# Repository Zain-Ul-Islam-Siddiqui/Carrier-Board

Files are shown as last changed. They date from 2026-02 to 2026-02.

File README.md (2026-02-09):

# Parking Access Control Carrier Board ([RK3568](https://www.alibaba.com/product-detail/YT-C68-Rockchip-RK3568-Quad-Core_1601366890205.html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) Linux Platform)
## Overview

Designed and implemented a high-performance carrier board for a Rockchip RK3568 compute module, targeting smart parking access control systems with support for multiple communication protocols and peripheral devices. The board serves as a centralized controller for barrier gates, ANPR cameras, intercom systems, ticket printers, and access readers in outdoor parking installations.

The system runs embedded Linux and provides a scalable hardware platform for field technicians and system integrators to deploy intelligent parking and access control solutions with wired and wireless connectivity, multimedia support, and industrial-grade reliability.

## Description
This project delivers a commercial-grade carrier board for a quad-core ARM Cortex-A76 based compute module (RK3568), designed specifically for parking access control and automation applications. The board integrates multiple industrial interfaces including Wiegand, RS232, RS485, Ethernet, USB, relay outputs, inductive loop inputs, and camera interfaces.

The carrier board enables real-time interaction with ANPR cameras, QR readers, intercom units, ticket printers, and barrier motors while providing a Linux-based software platform for UI, networking, and cloud connectivity. It supports both HDMI and MIPI-DSI displays with capacitive touch for operator interaction.

Designed for outdoor deployment, the hardware incorporates surge protection, ESD protection, wide-temperature operation, and power backup via Li-ion battery or supercapacitor to ensure continuous operation during power disturbances.

## Key Features
- RK3568 quad-core ARM Cortex-A76 Linux compute platform
- Multi-protocol access control support (Wiegand, RS232, RS485, GPIO, USB, Ethernet)
- Dual Ethernet interfaces for intercom and ANPR camera
- HDMI and MIPI-DSI display support with capacitive touchscreen
- Integrated relay outputs for barrier gate control (8 channels)
- Inductive loop detector inputs (3 channels)
- USB and CSI camera support (CCTV / pinhole camera)
- GSM/LTE connectivity via SIM module
- Wi-Fi and Bluetooth 5.0
- On-board environmental sensors (temperature and humidity)
- Battery / supercapacitor backup power support
- Outdoor-rated design with surge, ESD, and EMI protection
- Hardware status RGB LED and provisioning LEDs

## Technologies
- Rockchip RK3568 Compute Module
- Embedded Linux
- LPDDR4 RAM (minimum 4 GB, expandable)
- eMMC Flash (minimum 32 GB)
- USB 2.0 / 3.0
- Ethernet (10/100/1000 Mbps)
- HDMI + MIPI-DSI
- CSI Camera Interface
- GSM/LTE modem
- RS232 / RS485 / Wiegand
- Relays and opto-isolated GPIO
- Altium Designer

## Contribution
- Carrier board schematic design for RK3568 compute module
- High-speed PCB layout (DDR, HDMI, MIPI, Ethernet)
- Interface expansion for industrial IO (Wiegand, RS232, RS485, relays, GPIO)
- ESD, surge, and protection circuitry design
- Integration of GSM/LTE module and SIM interface
- Hardware bring-up preparation and validation planning

## Access Control Interfaces
Wiegand (1 primary + 1 optional)
RS232 (1 channel)
RS485 (1 channel)
Inductive loop detector (3 inputs)
Barrier gate control relays (8 outputs)
Activation LED (1 GPIO)
Status RGB LEDs (up to 6)

## Cameras & Imaging
ANPR camera via Ethernet
CCTV / pinhole camera via USB or CSI

## User Interface
HDMI display output
MIPI-DSI capacitive touchscreen
Optional action buttons (4 GPIO)
Intercom action button (1 GPIO)

## Connectivity
Dual Ethernet
USB (4 ports)
GSM/LTE with SIM card
Optional Wi-Fi & Bluetooth 5.0

## Audio
Microphone input
Speaker output

## Storage
eMMC (32 GB)
SD card slot (up to 512 GB)

## Electrical Specifications
- CPU: Quad-core ARM Cortex-A76 @ 2.4 GHz
- RAM: 4 GB LPDDR4 (expandable up to 32 GB)
- Storage: 32 GB eMMC + SD card
- Power Input: 12–24 V DC
- Backup Power: Li-ion battery

## Protection:
- Reverse polarity protection
- ESD protection on all IO
- Surge protection on Ethernet and inductive loop inputs
- EMI filtering

## Environmental Specifications
- Operating Temperature: -20°C to +65°C
- Humidity: 0% to 98% (non-condensing)
- Deployment: Outdoor parking systems
- Compliance Targets: CE & FCC

## PCB
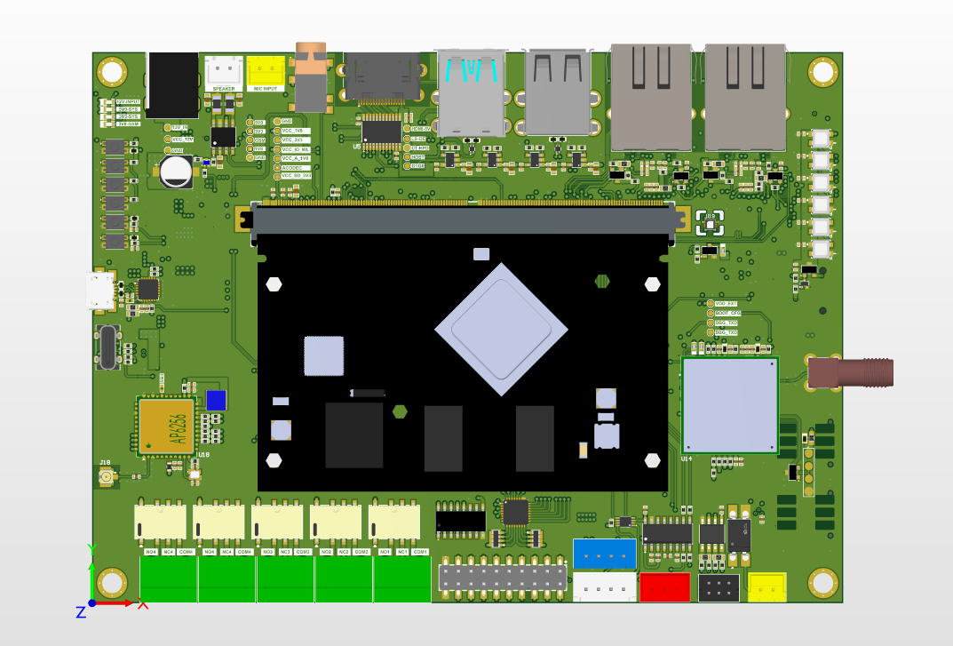
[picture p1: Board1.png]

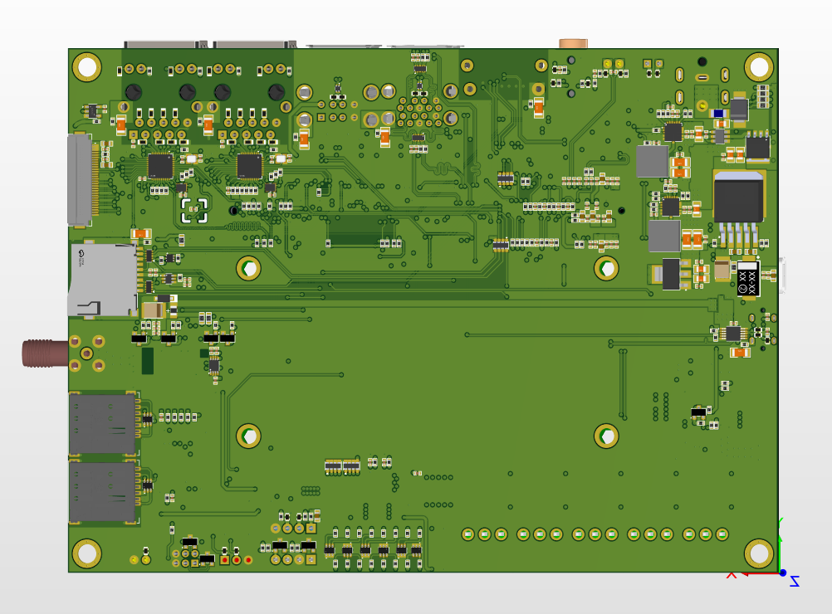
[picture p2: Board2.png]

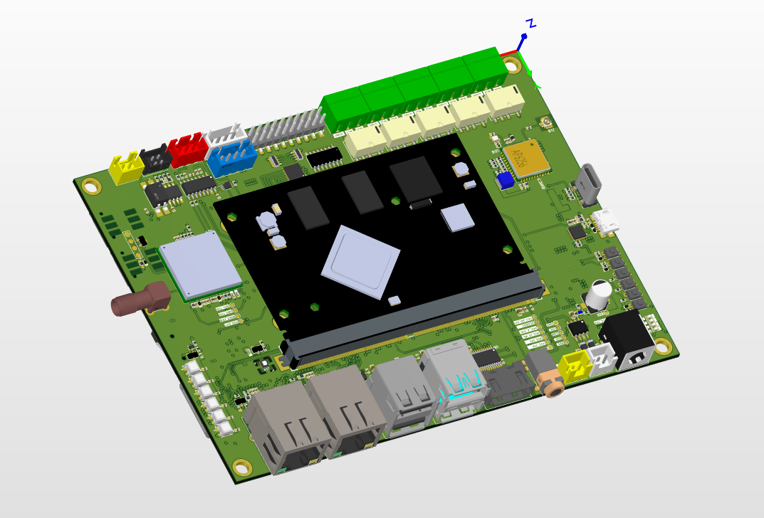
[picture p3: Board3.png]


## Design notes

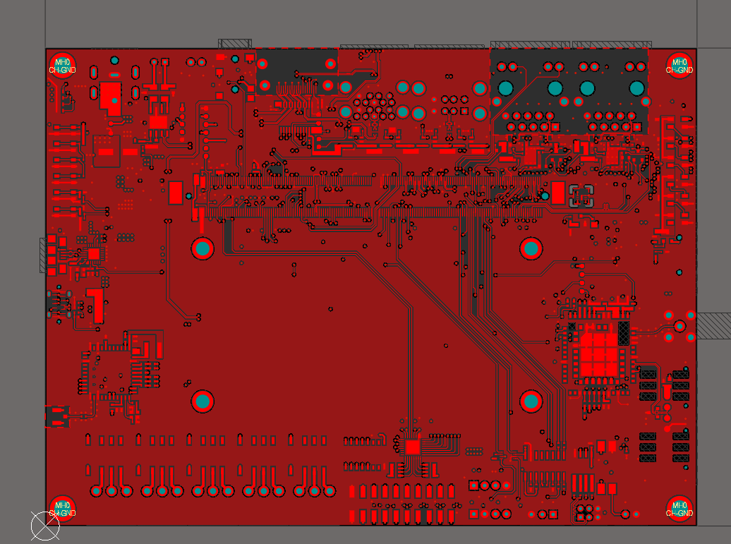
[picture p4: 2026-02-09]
Deliverables/Renderings/2D_Top_View.PNG

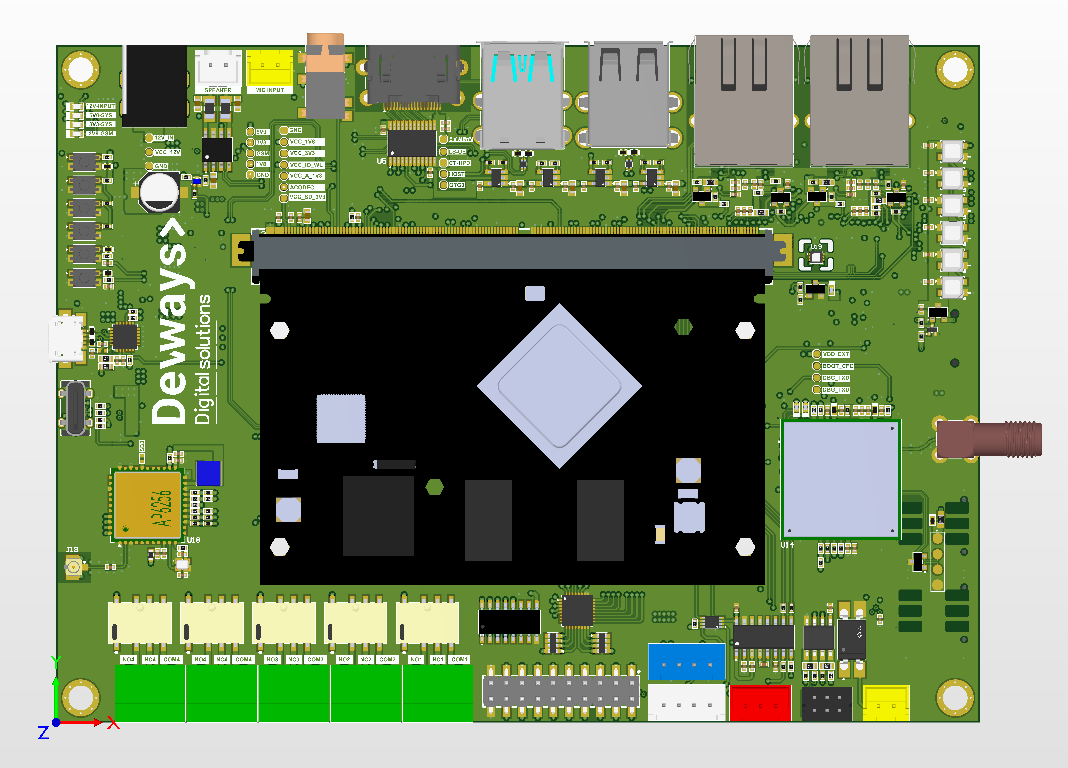
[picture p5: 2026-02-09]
Deliverables/Renderings/3D_Top_View.PNG

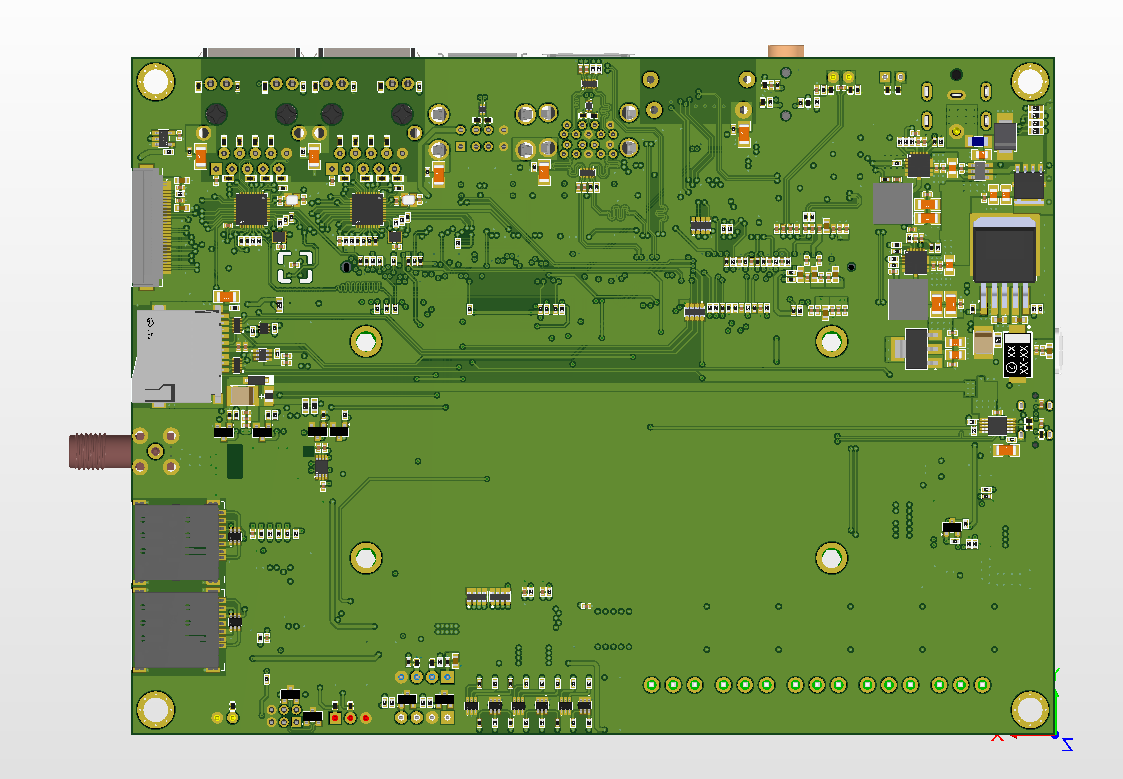
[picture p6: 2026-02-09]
Deliverables/Renderings/3D_Bottom_View.PNG

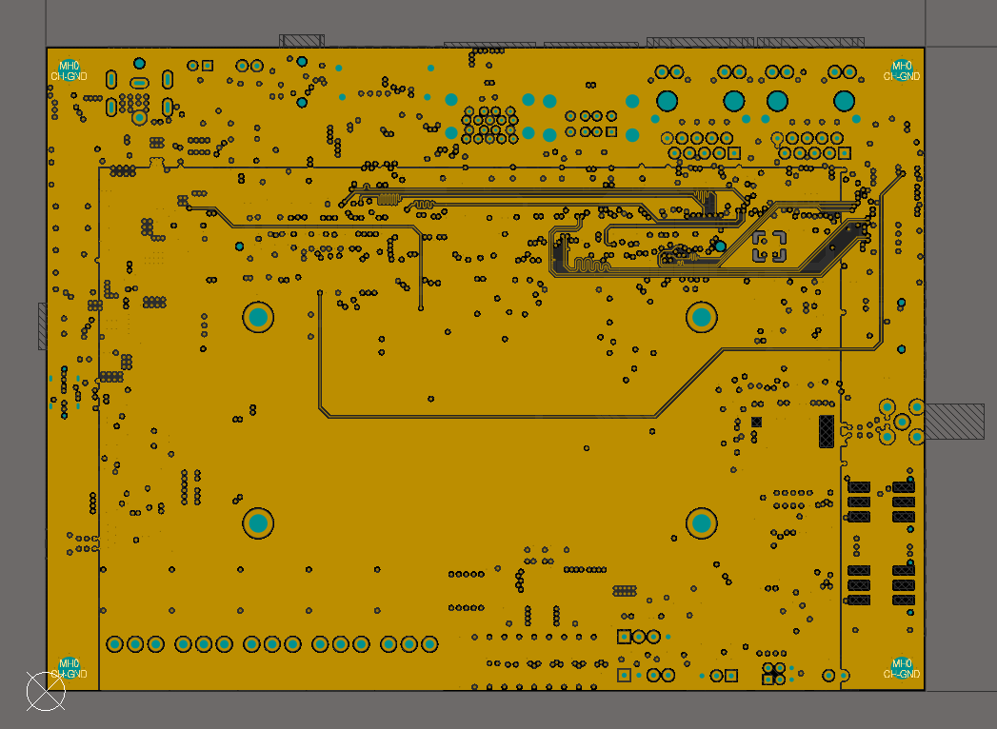
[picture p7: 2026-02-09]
Deliverables/Renderings/2D_L2_View.png

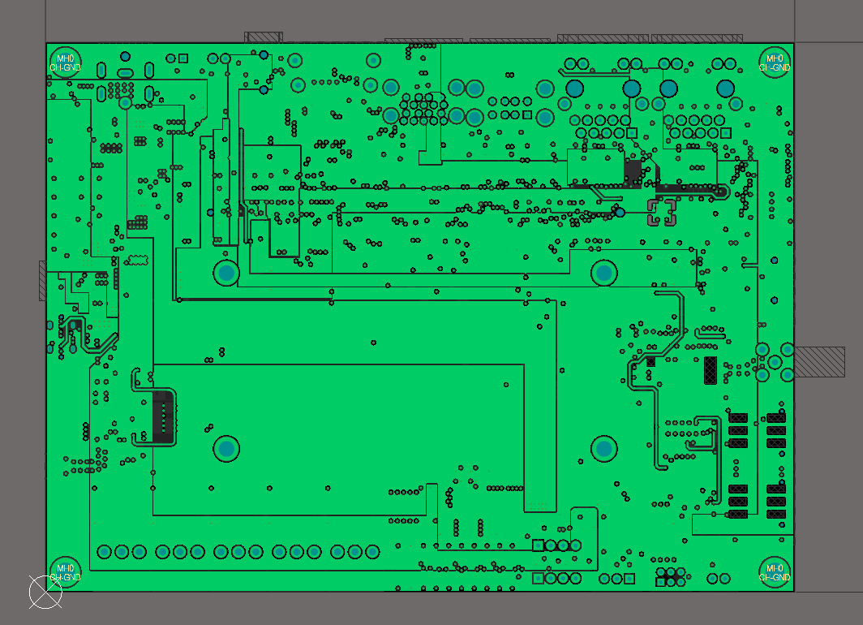
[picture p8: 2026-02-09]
Deliverables/Renderings/2D_L4_View.png

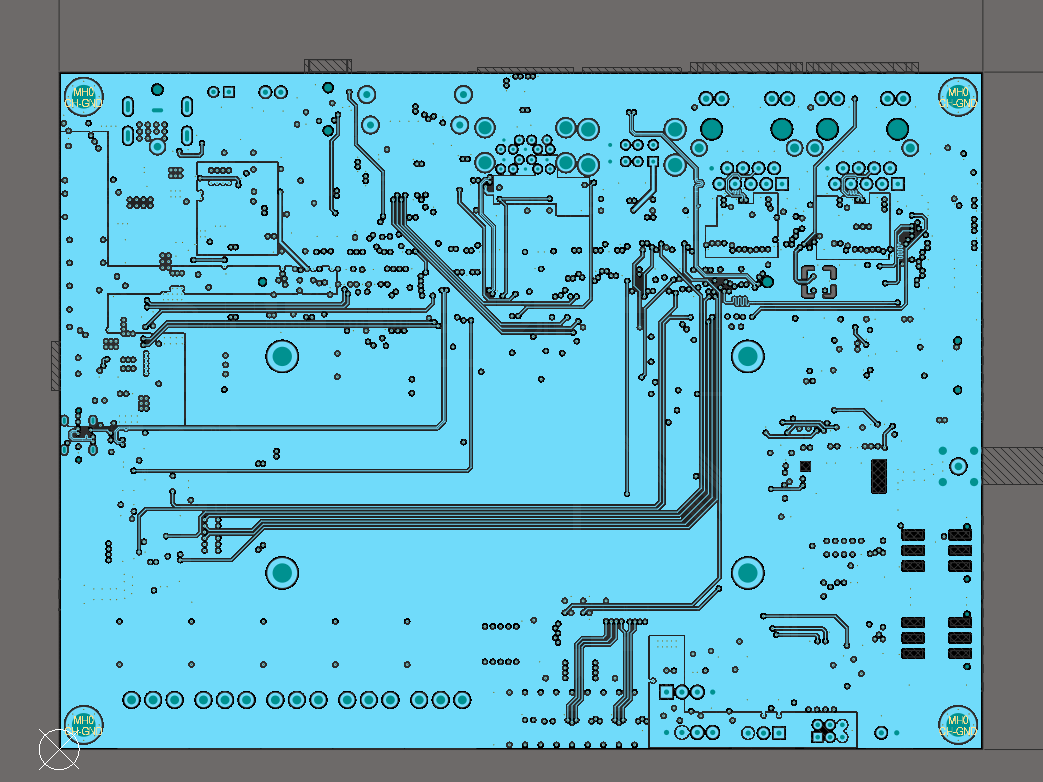
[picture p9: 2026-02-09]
Deliverables/Renderings/2D_L3_View.png

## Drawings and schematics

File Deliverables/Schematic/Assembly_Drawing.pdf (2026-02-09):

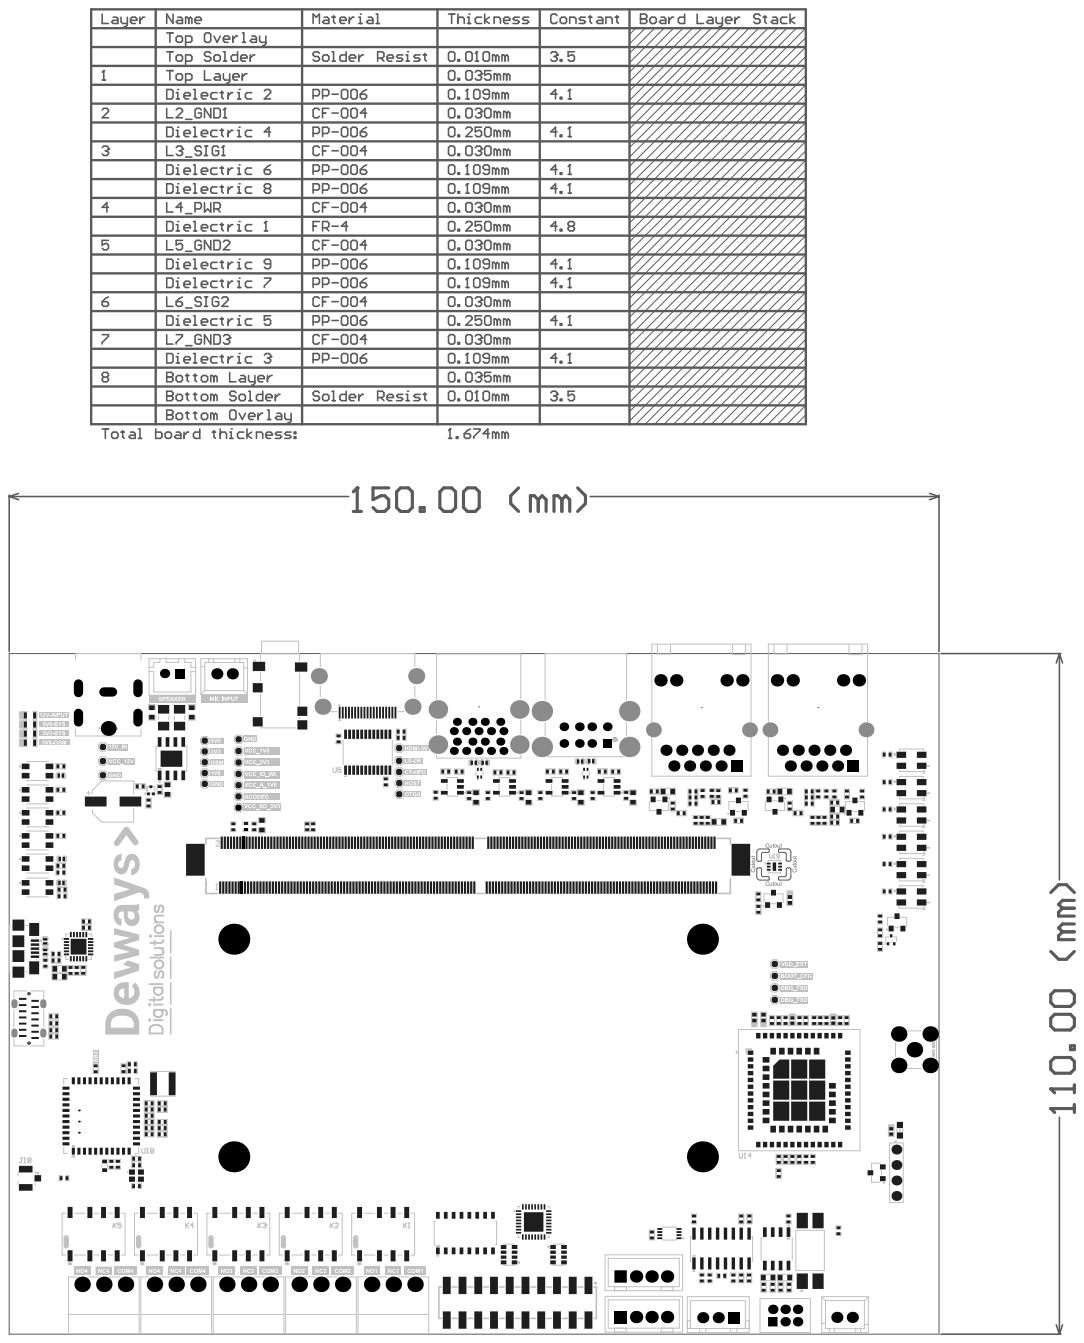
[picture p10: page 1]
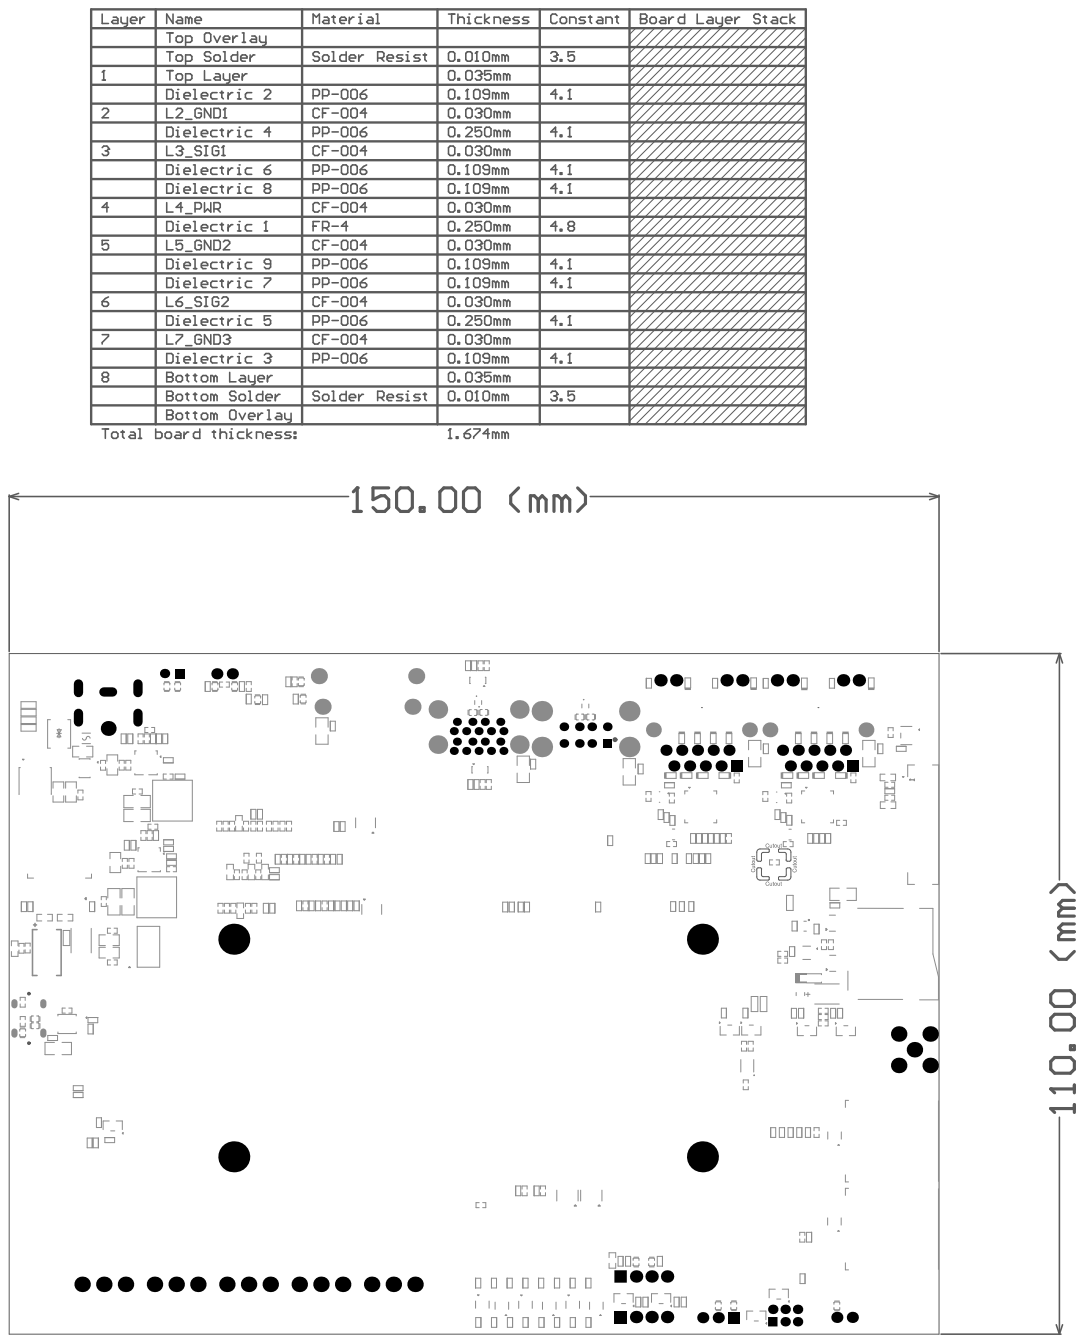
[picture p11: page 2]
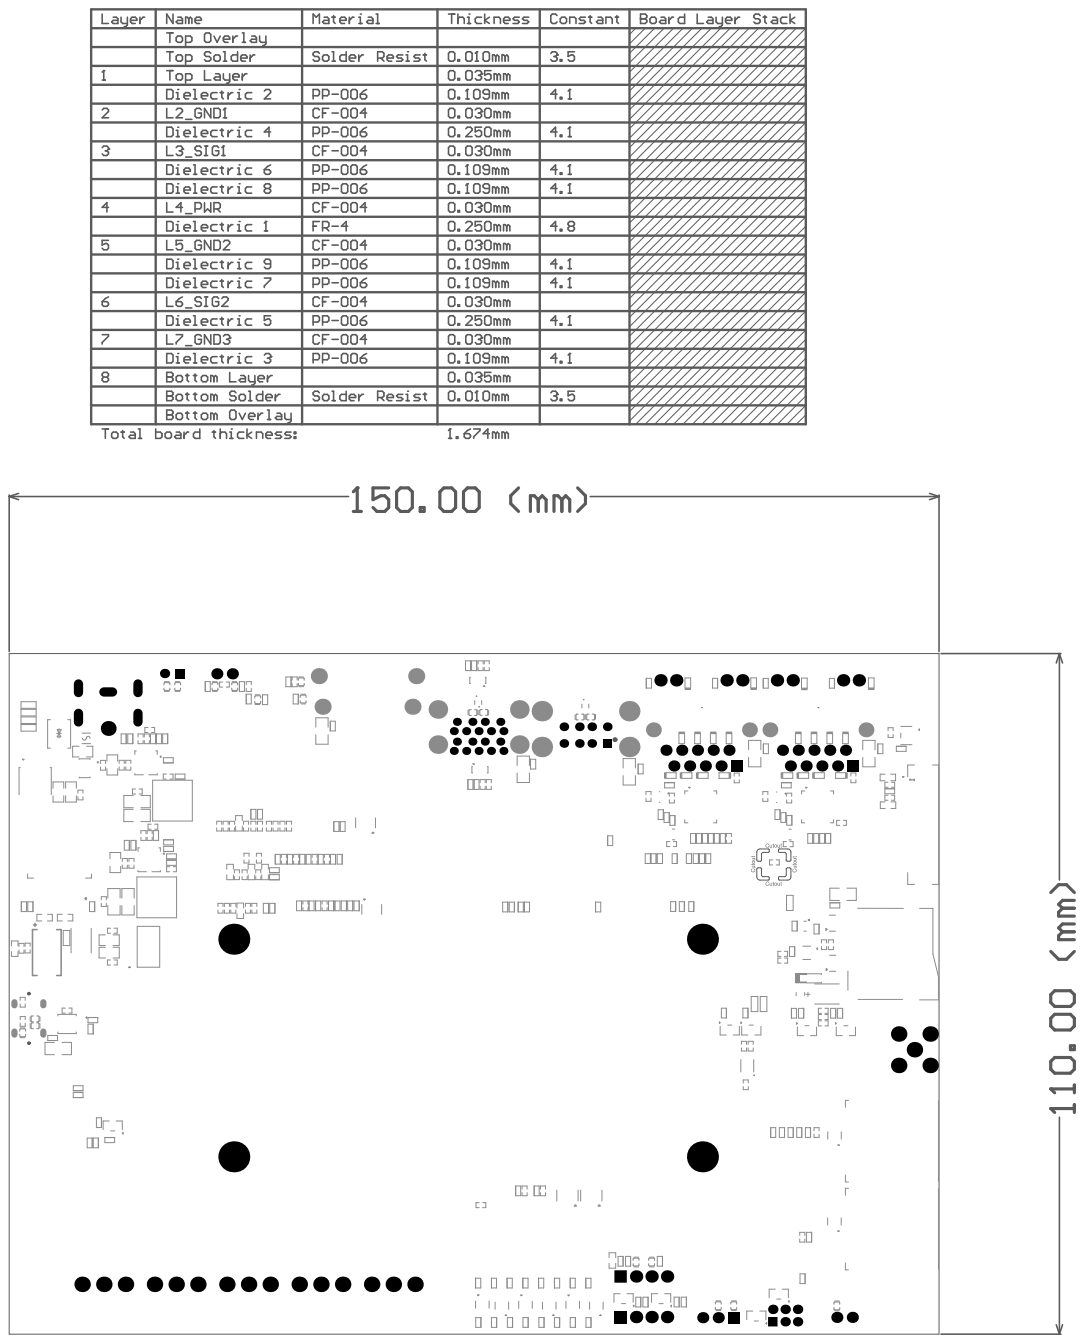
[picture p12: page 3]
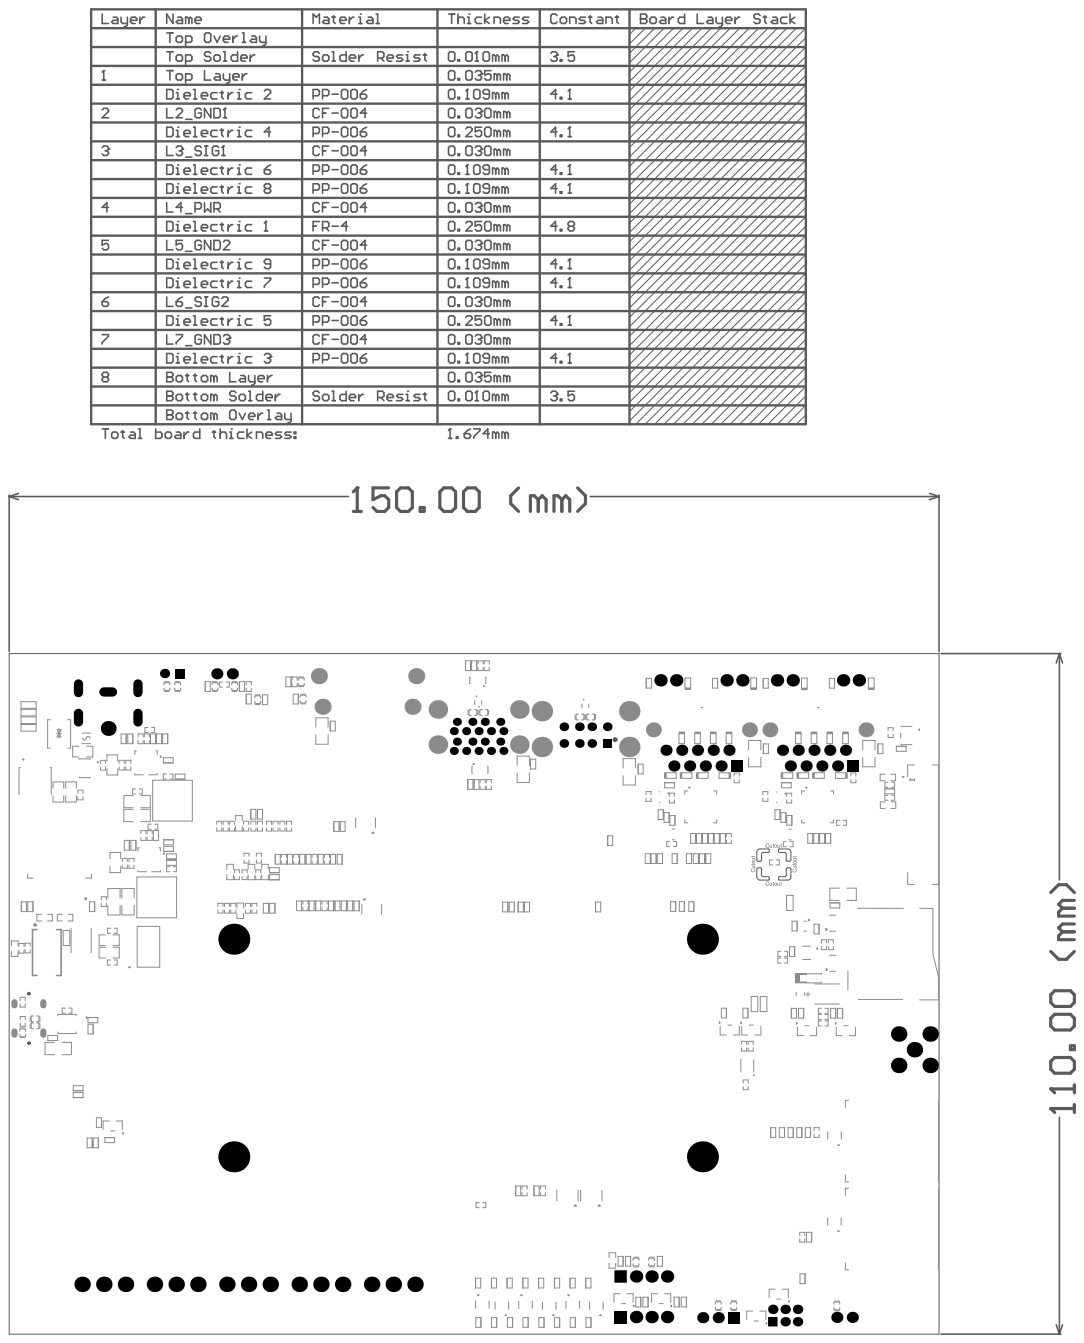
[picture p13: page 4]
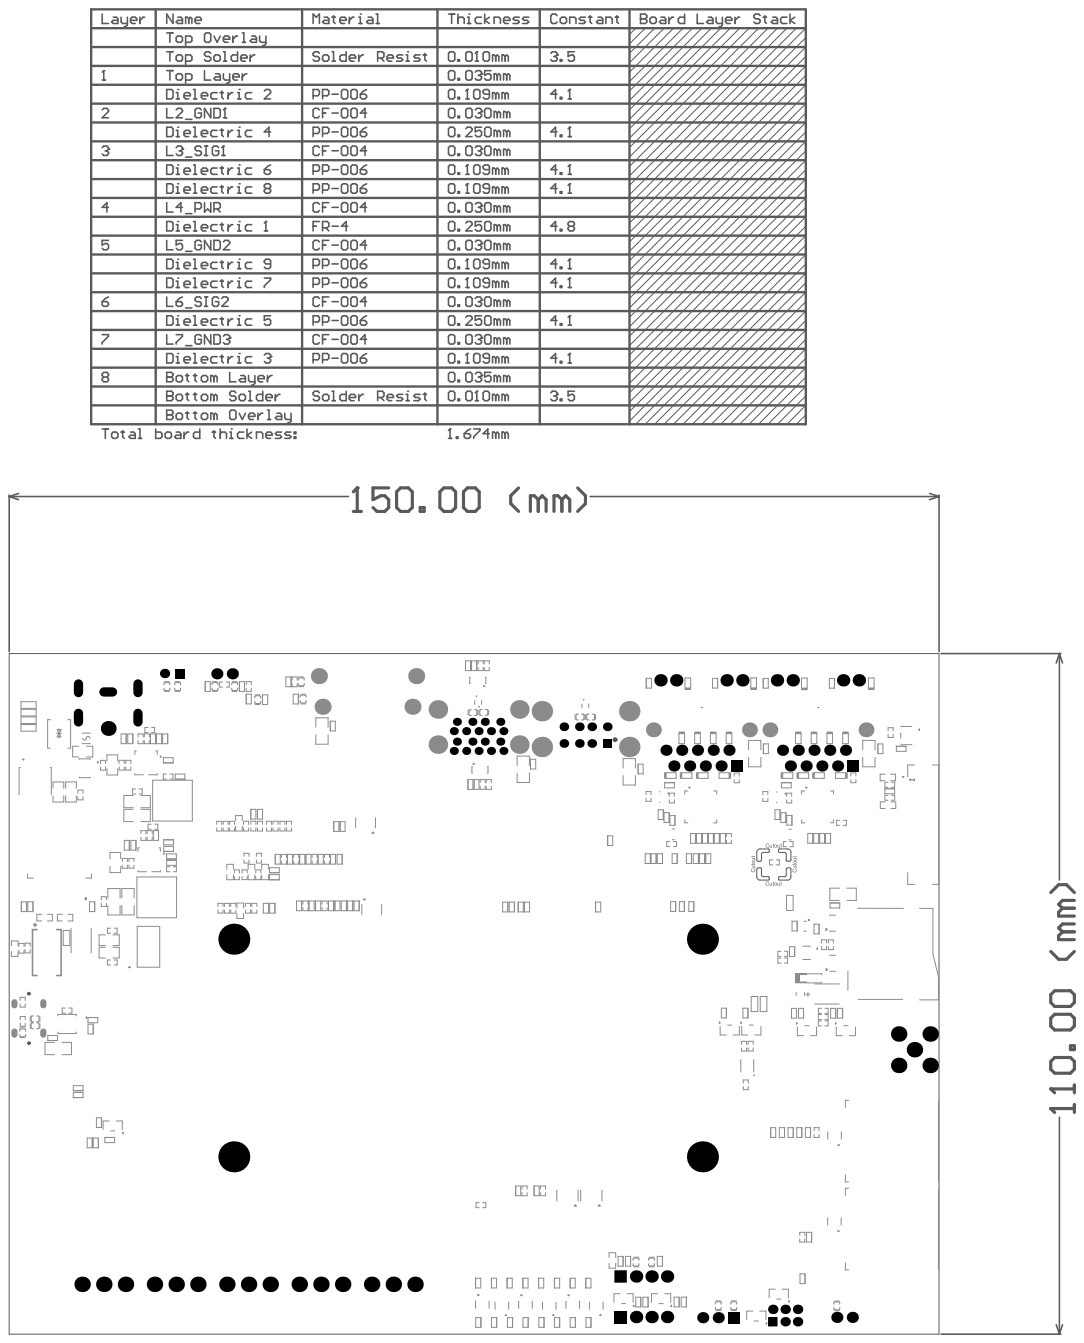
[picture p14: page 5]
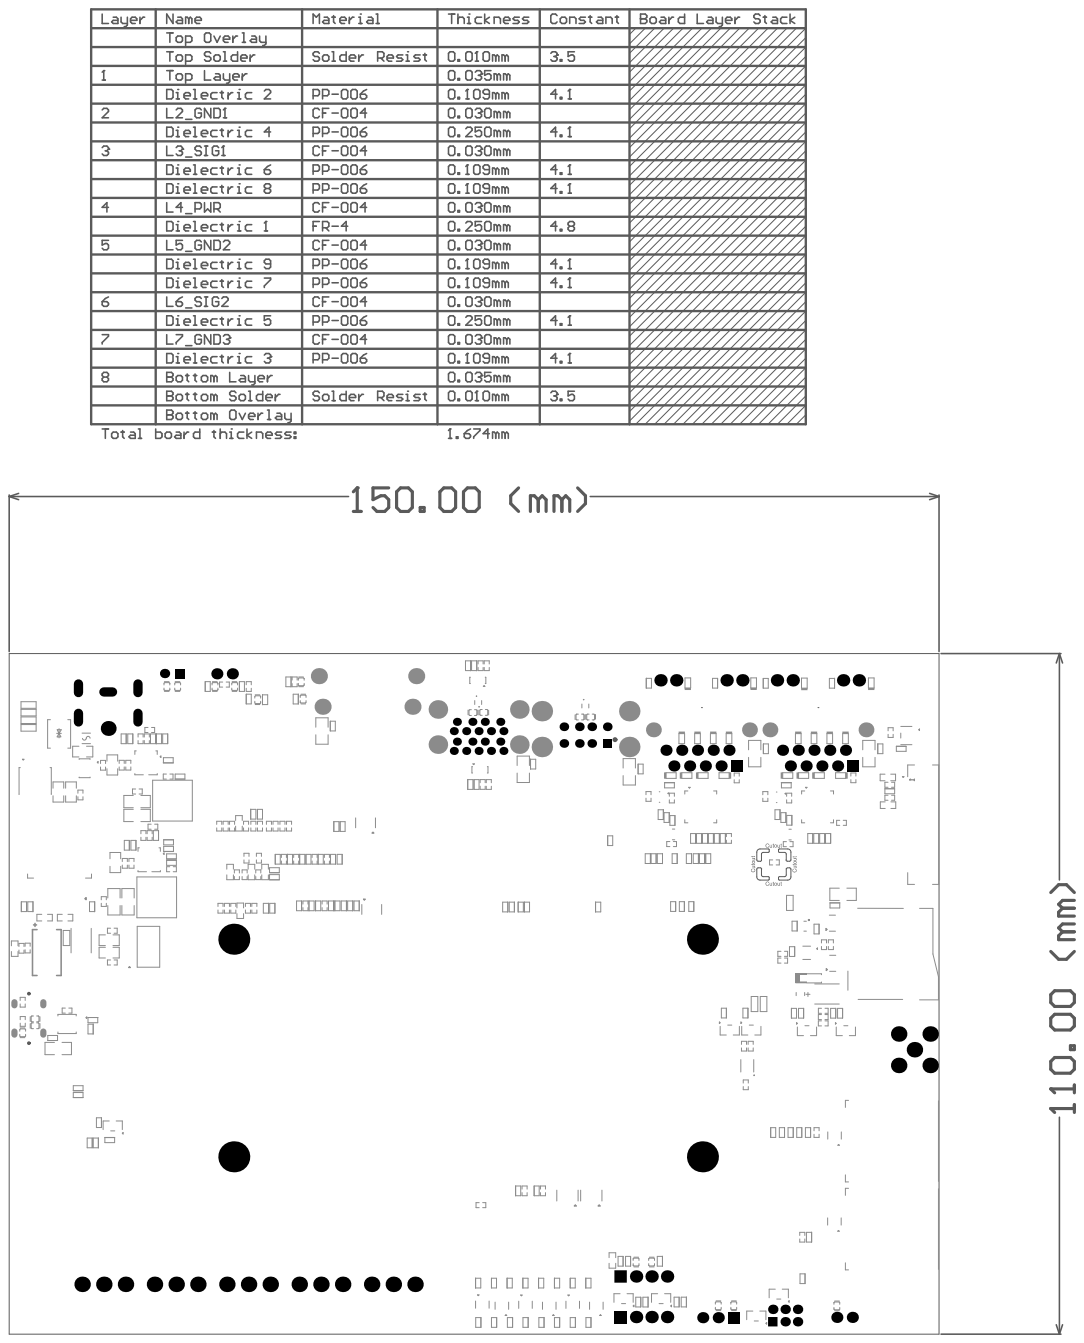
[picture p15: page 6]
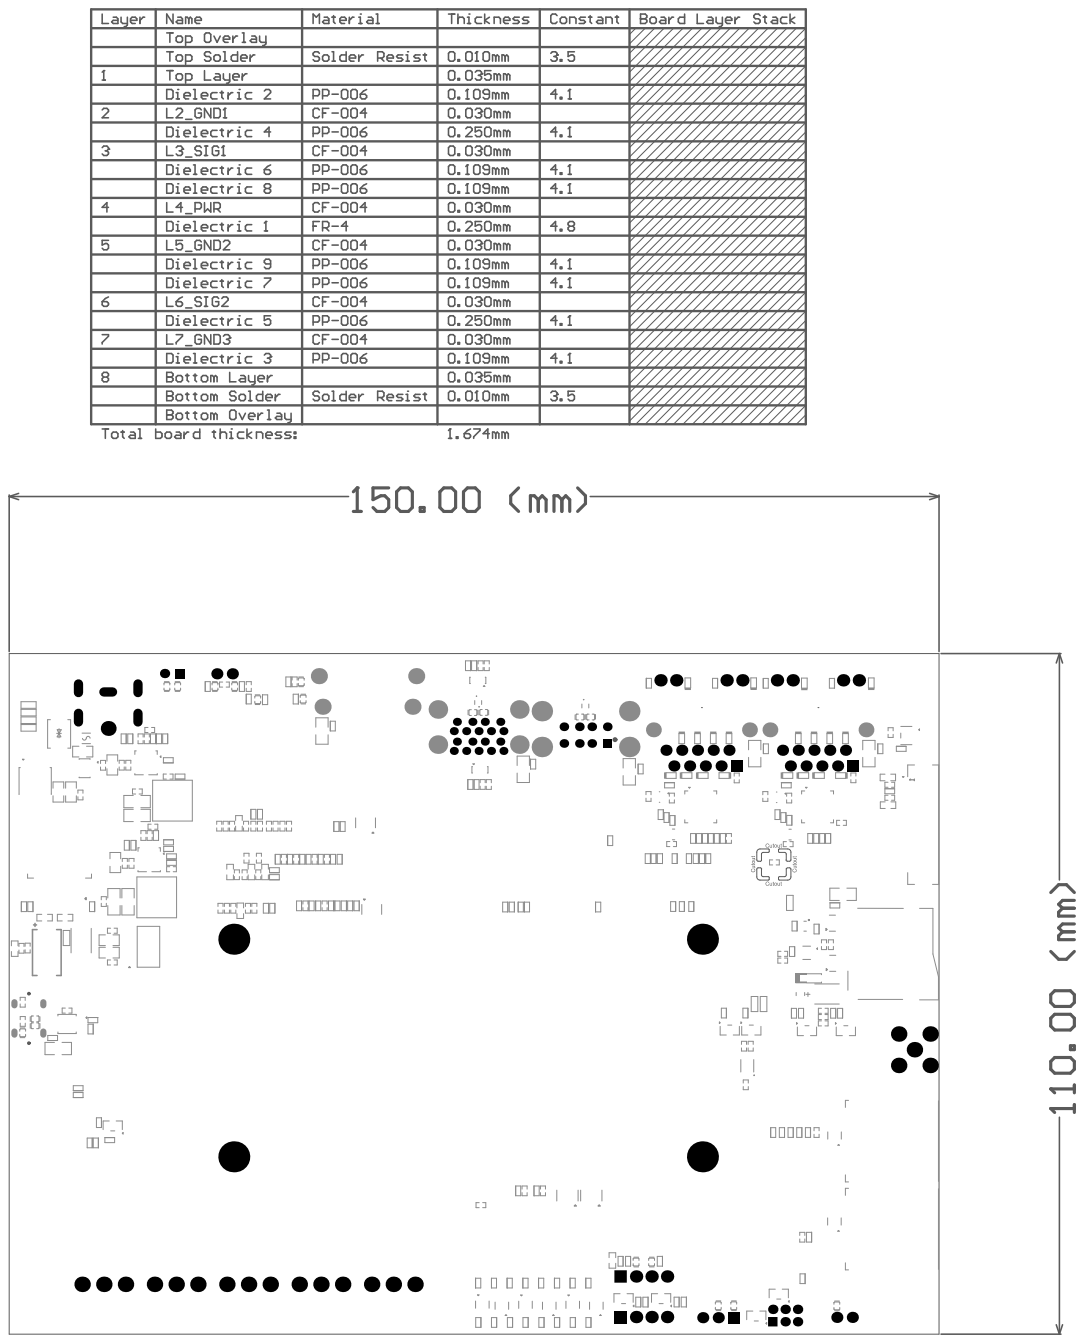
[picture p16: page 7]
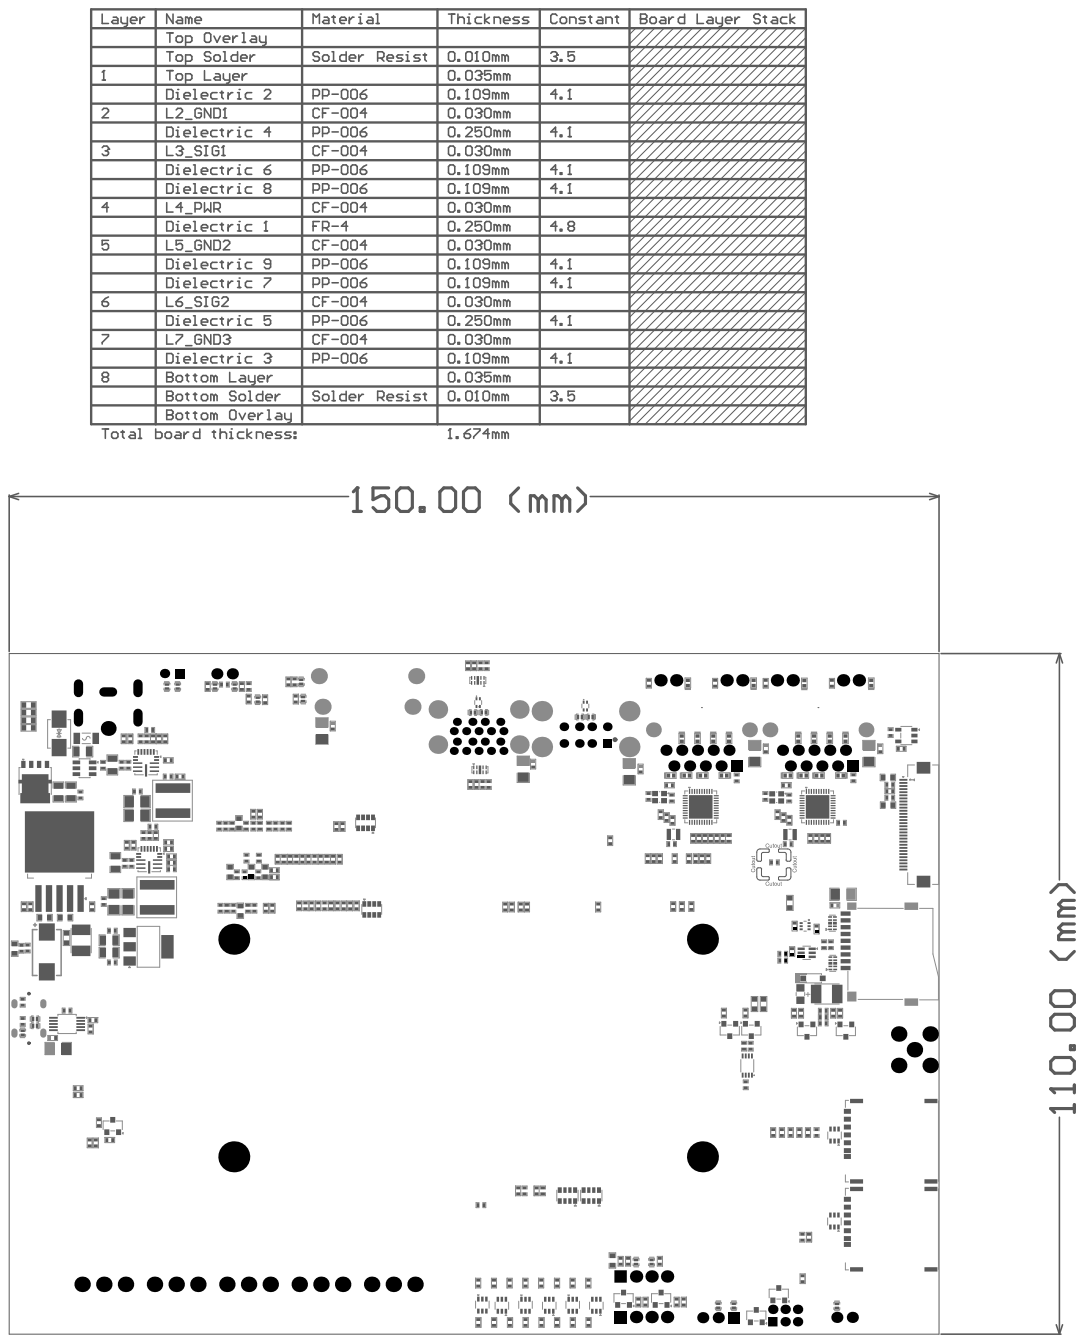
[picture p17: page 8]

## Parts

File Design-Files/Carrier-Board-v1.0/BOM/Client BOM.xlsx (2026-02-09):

# | Item Type | Designator | Description | Footprint | Manufacturer Part Number | Manufacturer | Value | Quantity | Quantity (3 Boards) | Links | Unit Cost (3 Boards) | Total Cost (3 Boards) | Remarks
1 | Capacitor | C1, C3, C4, C6, C7, C8, C9, C11, C12, C13, C14, C15, C16, C17, C18, C21, C22, C23, C27, C30, C34, C55, C65, C66, C67, C70, C71, C72, C75, C76, C78, C81, C84, C85, C88, C89, C91, C92, C93, C94, C95, C96, C97, C98, C100, C101, C103, C104, C106, C107, C109, C110, C111, C113, C114, C115, C118, C119, C120, C122, C126, C129, C131, C134, C135, C136, C137, C141, C143, C147, C148, C149, C152, C153, C154, C155, C158, C167, C168, C169, C180, C181, C182, C183, C184, C185, C186, C187, C188, C189, C190, C191, C192, C193, C194, C199, C204 | CAP CER 0.1UF 16V X5R 0402 | Cap-0402 | CC0402KRX5R7BB104 | Yageo | 100nF | 97 | 291 | Digikey (https://www.digikey.com/en/products/detail/yageo/CC0402KRX5R7BB104/2103085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) | $0.0107 | $3.1137
2 | Capacitor | C2, C165 | CAP CER 100PF 50V C0G/NPO 0402 | Cap-0402 | CC0402JRNPO9BN101 | Yageo | 100pF | 2 | 6 | Digikey (https://www.digikey.com/en/products/detail/yageo/CC0402JRNPO9BN101/302758) | $0.1000 | $0.6000
3 | Capacitor | C5, C10, C24, C31, C125, C142, C203 | CAP CER 1000PF 2KV X7R 1206 | Cap-1206 | CC1206KKX7RDBB102 | Yageo | 1nF | 7 | 21 | Digikey (https://www.digikey.com/en/products/detail/yageo/CC1206KKX7RDBB102/2833652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) | $0.2090 | $4.3890
4 | Capacitor | C19, C25, C28, C32 | CAP CER 1UF 16V X5R 0402 | Cap-0402 | CC0402KRX5R7BB105 | Yageo | 1uF | 4 | 12 | Digikey (https://www.digikey.com/en/products/detail/yageo/CC0402KRX5R7BB105/5195100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) | $0.1450 | $1.7400
5 | Capacitor | C20, C26, C29, C33 | CAP CER 10UF 16V X5R 0603 | Cap-0603 | CC0603KRX5R7BB106 | Yageo | 10uF | 4 | 12 | Digikey (https://www.digikey.com/en/products/detail/yageo/CC0603KRX5R7BB106/7164370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) | $0.4560 | $5.4720
6 | Capacitor | C35, C36, C38 | CAP CER 4.7UF 50V X5R 0805 | Cap-0805 | GRM21BR61H475KE51L | Murata | 4.7uf | 3 | 9 | Digikey (https://www.digikey.com/en/products/detail/murata-electronics/GRM21BR61H475KE51L/4905540) | $0.2800 | $2.5200
7 | Capacitor | C37, C68, C80, C166 | CAP CER 1UF 25V X5R 0402 | Cap-0402 | CC0402KRX5R8BB105 | Yageo | 1uF | 4 | 12 | Digikey (https://www.digikey.com/en/products/detail/yageo/CC0402KRX5R8BB105/5195107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) | $0.1730 | $2.0760
8 | Capacitor | C39, C40, C42, C43, C46, C50, C52, C53, C57, C124, C130, C177, C179 | CAP CER 0.1UF 50V X7R 0402 | cap-0402 | C1005X7R1H104KT000F | TDK | 100nF | 13 | 39 | Digikey (https://www.digikey.com/en/products/detail/tdk-corporation/C1005X7R1H104K050BB/2443410) | $0.0560 | $2.1840
9 | Capacitor | C41, C51, C176, C178 | CAP CER 10UF 50V X5R 0805 | Cap-0805 | GRM21BR61H106ME43L | Murata | 10uF | 4 | 12 | Digikey (https://www.digikey.com/en/products/detail/murata-electronics/GRM21BR61H106ME43L/10326317) | $0.2240 | $2.6880
10 | Capacitor | C44, C45, C54, C56 | CAP CER 47UF 25V X5R 1206 | Cap-1206 | GRM31CR61E476ME44L | Murata | 47uF | 4 | 12 | Digikey (https://www.digikey.com/en/products/detail/murata-electronics/GRM31CR61E476ME44K/13910174) | $0.7530 | $9.0360
11 | Capacitor | C47, C59 | CAP CER 2.2UF 25V X5R 0402 | Cap-0402 | GRM155R61E225KE11D | Murata | 2.2uf | 2 | 6 | Digikey (https://www.digikey.com/en/products/detail/murata-electronics/GRM155R61E225KE11D/4905143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) | $0.2200 | $1.3200
12 | Capacitor | C48, C60 | CAP CER 1000PF 25V X7R 0402 | Cap-0402 | CC0402KRX7R8BB102 | Yageo | 1000pF | 2 | 6 | Digikey (https://www.digikey.com/en/products/detail/yageo/CC0402KRX7R8BB102/5195121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) | $0.1000 | $0.6000
13 | Capacitor | C49, C61 | CAP CER 3.9PF 50V C0G/NPO 0402 | Cap-0402 | CC0402BRNPO9BN3R9 | Yageo | 3.9pF | 2 | 6 | Digikey (https://www.digikey.com/en/products/detail/yageo/CC0402BRNPO9BN3R9/5195031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) | $0.1000 | $0.6000
14 | Capacitor | C58, C77 | CAP CER 10PF 50V C0G/NP0 0402 | Cap-0402 | GRM1555C1H100JA01D | Murata | 10pF | 2 | 6 | Digikey (https://www.digikey.com/en/products/detail/murata-electronics/GRM1555C1H100JA01D/3661907) | $0.1000 | $0.6000
15 | Capacitor | C62 | CAP TANT 470UF 10% 10V 2917 | Case-E | TAJE477K010RNJ | Kyocera AVX | 470uF | 1 | 3 | Digikey (https://www.digikey.com/en/products/detail/kyocera-avx/TAJE477K010RNJ/563853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) | $2.3700 | $7.1100
16 | Capacitor | C63 | CAP CER 0.1UF 50V X5R 0603 | Cap-0603 | CC0603KRX5R9BB104 | Yageo | 100nF | 1 | 3 | Digikey (https://www.digikey.com/en/products/detail/yageo/CC0603KRX5R9BB104/5883729) | $0.1000 | $0.3000
17 | Capacitor | C64 | CAP CER 33PF 25V C0G/NP0 0402 | Cap-0402 | GRM1555C1E330JA01D | Murata | 33pF | 1 | 3 | Digikey (https://www.digikey.com/en/products/detail/murata-electronics/GRM1555C1E330JA01D/3693730) | $0.1000 | $0.3000
18 | Capacitor | C69, C174 | CAP TANT 100UF 20% 10V 1411 | Case-B | TAJB107M010RNJ | Kyocera AVX | 100uF | 2 | 6 | Digikey (https://www.digikey.com/en/products/detail/kyocera-avx/TAJB107M010RNJ/1469629) | $0.6900 | $4.1400
19 | Capacitor | C73, C74 | CAP CER 0.22UF 25V X5R 0402 | Cap-0402 | CC0402KRX5R8BB224 | Yageo | 220nF | 2 | 6 | Digikey (https://www.digikey.com/en/products/detail/yageo/CC0402KRX5R8BB224/5883337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) | $0.1000 | $0.6000
20 | Capacitor | C79 | CAP CER 10UF 10V X5R 0402 | Cap-0402 | CC0402MRX5R6BB106 | Yageo | 10uF | 1 | 3 | Digikey (https://www.digikey.com/en/products/detail/yageo/CC0402MRX5R6BB106/7164364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) | $0.2600 | $0.7800
21 | Capacitor | C82, C83, C127, C128, C138, C139 | CAP CER 12PF 50V C0G/NP0 0402 | Cap-0402 | GJM1555C1H120GB01D | Murata | 12pF | 6 | 18 | Digikey (https://www.digikey.com/en/products/detail/murata-electronics/GJM1555C1H120GB01D/2592851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) | $0.1900 | $3.4200
22 | Capacitor | C86, C87, C90, C99, C102, C105, C108, C112, C156, C157 | CAP CER 10UF 25V X5R 0603 | Cap-0603 | C1608X5R1E106M080AC | TDK | 10uF | 10 | 30 | Digikey (https://www.digikey.com/en/products/detail/tdk-corporation/C1608X5R1E106M080AC/3648585) | $0.2700 | $8.1000
23 | Capacitor | C116 | 100uF 50V ±20% SMD,D6.3xL7.7mm Aluminum Electrolytic Capacitors - SMD ROHS | Custom | RVT1H101M0607 | ROQANG | 100uF | 1 | 3 | LCSC (https://www.lcsc.com/product-detail/Aluminum-Electrolytic-Capacitors-SMD_ROQANG-RVT1H101M0607_C3151829.html) | $0.0568 | $0.1704
24 | Capacitor | C117, C121, C123, C132, C140, C146, C150 | CAP CER 4.7UF 10V X5R 0402 | Cap-0402 | CC0402KRX5R6BB475 | Yageo | 4.7uF | 7 | 21 | Digikey (https://www.digikey.com/en/products/detail/yageo/CC0402KRX5R6BB475/7164361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) | $0.0820 | $1.7220
25 | Capacitor | C159, C160, C161, C162, C163, C164, C198 | CAP CER 1000PF 25V X7R 0402 | Cap-0402 | CC0402KRX7R8BB102 | Yageo | 1nF | 7 | 21 | Digikey (https://www.digikey.com/en/products/detail/yageo/CC0402KRX7R8BB102/5195121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) | $0.0210 | $0.4410
26 | Capacitor | C170, C171 | CAP CER 27PF 25V C0G/NP0 0402 | Cap-0402 | 0402N270J250CT | Walsin Technologies | 27pF | 2 | 6 | Digikey (https://www.digikey.com/en/products/detail/walsin-technology-corporation/0402N270J250CT/9354788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) | $0.1000 | $0.6000
27 | Capacitor | C172, C173 | CAP CER 0.015UF 50V X7R 0402 | Cap-0402 | CC0402KRX7R9BB153 | Yageo | 15nF | 2 | 6 | Digikey (https://www.digikey.com/en/products/detail/yageo/CC0402KRX7R9BB153/5883374) | $0.1000 | $0.6000
28 | Capacitor | C175 | CAP CER 0.1UF 100V X7R 0603 | Cap-0603 | CC0603KRX7R0BB104 | Yageo | 0.1uF | 1 | 3 | Digikey (https://www.digikey.com/en/products/detail/yageo/CC0603KRX7R0BB104/3476111) | $0.1700 | $0.5100
29 | Capacitor | C195, C196 | CAP CER 1000PF 25V C0G/NPO 0603 | CAP-0603 | CC0603JRNPO8BN102 | Yageo | 1000pF | 2 | 6 | Digikey (https://www.digikey.com/en/products/detail/yageo/CC0603JRNPO8BN102/2103080) | $0.1000 | $0.6000
30 | Capacitor | C197 | CAP CER 1UF 25V X5R 0603 | Cap-0603 | CC0603KRX5R8BB105 | Yageo | 1uF | 1 | 3 | Digikey (https://www.digikey.com/en/products/detail/yageo/CC0603KRX5R8BB105/2833610) | $0.1000 | $0.3000
31 | Surge Protection (TVS/ESD) | D1, D2 | TVS DIODE 7V/12V 14V/26V SOT23-3 | SOT-23 | CDSOT23-SM712 | Bourns | - | 2 | 6 | Digikey (https://www.digikey.com/en/products/detail/bourns-inc/CDSOT23-SM712/1630592) | $1.5000 | $9.0000
32 | Diode | D3, D4, D7, D8, D9, D10, D11, D12, D13, D14, D22, D23, D24, D25, D48, D49, D50, D51, D53, D54, D55, D56, D57, D61, D64, D65, D66, D68 | DFN1006-2(0402) ESD Protection Devices ROHS | DFN1006-2L (Bi-Directional) | ESD5451N | TECH PUBLIC | - | 28 | 84 | LCSC (https://www.lcsc.com/product-detail/Electrostatic-and-Surge-Protection-TVS-span-style-background-color-ff0-ESD-span_TECH-PUBLIC-ESD5451N_C2936977.html) | $0.0083 | $0.6972
33 | Diode | D5, D6 | DFN2510-10L ESD Protection Devices ROHS | DFN2510-10L_ | ESD5344D-10/TR | WILLSEMI | - | 2 | 6 | LCSC (https://www.lcsc.com/product-detail/Electrostatic-and-Surge-Protection-TVS-span-style-background-color-ff0-ESD-span_WILLSEMI-Will-Semicon-ESD5344D-10-TR_C2396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) | $0.0626 | $0.3756
34 | Diode | D15 | TVS DIODE 33VWM 53.3VC SMB | SMB Bi Directional | SMBJ33CA-13-F | Diodes | - | 1 | 3 | Digikey (https://www.digikey.com/en/products/detail/diodes-incorporated/SMBJ33CA-13-F/814613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) | $0.3700 | $1.1100
35 | Diode | D16, D58, D59, D60, D62, D63 | DIODE ZENER ARRAY 3.3V SOT363 | SOT-363 | BZX84C3V3TS-7-F | Diodes Incorporated | - | 6 | 18 | Digikey (https://www.digikey.com/en/products/detail/diodes-incorporated/BZX84C3V3TS-7-F/1934541) | $0.3050 | $5.4900
36 | Diode | D17 | DIODE ZENER 5.1V 500MW SOD123 | SOD-123 | MMSZ5231BT1G | ON Semiconductor | - | 1 | 3 | Digikey (https://www.digikey.com/en/products/detail/onsemi/MMSZ5231BT1G/919749) | $0.2100 | $0.6300
37 | Diode | D18, D26, D27, D28, D29, D30, D31, D32, D33, D34, D35, D36, D37, D38, D39, D40, D41, D42, D43, D44, D45 | DFN1006-2 ESD Protection Devices ROHS | DFN1006-2L_ | ESD9X5VU | TECH PUBLIC | - | 21 | 63 | LCSC (https://www.lcsc.com/product-detail/Electrostatic-and-Surge-Protection-TVS-span-style-background-color-ff0-ESD-span_TECH-PUBLIC-ESD9X5VU_C2875160.html) | $0.0191 | $1.2033
38 | Diode | D19 | 16A 20V 7V 5V@Max Unidirectional SOT-23 TVS ROHS | Sot-23 | ESD5302F-3/TR | WILLSEMI | - | 1 | 3 | LCSC (https://www.lcsc.com/product-detail/Electrostatic-and-Surge-Protection-TVS-span-style-background-color-ff0-ESD-span_WILLSEMI-Will-Semicon-ESD5302F-3-TR_C23964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) | $0.0794 | $0.2382
39 | Diode | D20, D21 | 35A@8/20us 15V 4.5V@Max DFN1006-2L Electrostatic and Surge Protection (TVS/ESD) ROHS | DFN1006-2L_ | ESD5651N-2/TR | WILLSEMI(Will Semicon) | - | 2 | 6 | LCSC (https://www.lcsc.com/product-detail/Electrostatic-and-Surge-Protection-TVS-span-style-background-color-ff0-ESD-span_WILLSEMI-Will-Semicon-ESD5651N-2-TR_C23978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) | $0.0291 | $0.1746
40 | (TVS/ESD) | D46, D47 | TVS DIODE 5.5VWM SOT23 | SOT-23 | DRTR5V0U1SO-7 | Diodes | - | 2 | 6 | Digikey (https://www.digikey.com/en/products/detail/diodes-incorporated/DRTR5V0U1SO-7/4457873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) | $0.3400 | $2.0400
41 | Fuse | F1 | FUSE BRD MNT 5A 32VAC 75VDC 1206 | Fuse 1206 (3216 Metric) | 0458005.DR | Littelfuse | - | 1 | 3 | Digikey (https://www.digikey.com/en/products/detail/littelfuse-inc/0458005-DR/1963347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) | $1.6600 | $4.9800
42 | Fuse | F2 | 6V 500mA 40A 1A 0603 Resettable Fuses ROHS | Fuse-0603 | SMD0603-050 | TECHFUSE | - | 1 | 3 | LCSC (https://www.lcsc.com/product-detail/Resettable-Fuses_TECHFUSE-SMD0603-050_C69679.html) | $0.0394 | $0.1182
43 | Ferrite Bead | FB1 | FERRITE BEAD 30 OHM 0805 1LN | Ind-0805 | BLM21PG300SN1D | Murata | - | 1 | 3 | Digikey (https://www.digikey.com/en/products/detail/murata-electronics/BLM21PG300SN1D/584262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) | $0.1200 | $0.3600
44 | Ferrite Bead | FB2 | 0603 180Ω ±25% DCR=0.09Ω 1.5A | IND-0603 (1608 Metric) | BLM18PG181SN1D | Murata | - | 1 | 3 | Digikey (https://www.digikey.com/en/products/detail/murata-electronics/BLM18PG181SN1D/1634634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) | $0.1000 | $0.3000
45 | Ferrite Bead | FB3, FB4 | FERRITE BEAD 1K OHM 1206 1LN | IND-1206 | BLM31KN102SN1L | Murata | - | 2 | 6 | Digikey (https://www.digikey.com/en/products/detail/murata-electronics/BLM31KN102SN1L/7564086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) | $0.3200 | $1.9200
46 | MicroSD card | J1 | 2mm Deck MicroSD card (TF card) Self bomb SMD SD Card / Memory Card Connector ROHS | Custom | TF-01A | Yuandi | - | 1 | 3 | LCSC (https://www.lcsc.com/product-detail/SD-Card-Memory-Card-Connector_Yuandi-TF-01A_C2889258.html) | $0.0741 | $0.2223
47 | Card Edge Connectors | J1 Part- | SMD,P=0.5mm,Surface Mount，Right Angle | Custom | AS0B826-S78B-7H | FOXCONN | - | 1 | 3 | LCSC (https://www.lcsc.com/product-detail/Card-Edge-Connectors_FOXCONN-AS0B826-S78B-7H_C426232.html) | $4.2946 | $12.8838
48 | HDMI Connector | J2 | CONN RCPT 1.4 HDMI 19POS SMD R/A | Custom | 10029449-111RLF | Amphenol ICC / FCI | - | 1 | 3 | Digikey (https://www.digikey.com/en/products/detail/amphenol-cs-fci/10029449-111RLF/2785386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) | $1.2600 | $3.7800
49 | Wire To Board Connector | J3 | 2x3P 2 2mm 2mm male 3 -25℃~+85℃ 3A Straight Plugin,P=2mm Wire To Board / Wire To Wire Connector ROHS | Custom | HX20012-6A black | HX(Zhejiang Yueqing Hongxing Elec) | - | 1 | 3 | LCSC (https://www.lcsc.com/product-detail/Wire-To-Board-Connector_HX-Zhejiang-Yueqing-Hongxing-Elec-HX20012-6A-black_C469723.html) | $0.0426 | $0.1278
50 | Wire To Board Connector | J4 | 1x3P 3P XH 1 Tin 2.5mm 3 -25℃~+85℃ Brass 3A Straight Plugin,P=2.5mm Wire To Board Connector ROHS | Custom | HC-XH-3A-R | HCTL | - | 1 | 3 | LCSC (https://www.lcsc.com/product-detail/Wire-To-Board-Connector_HCTL-HC-XH-3A-R_C7466690.html) | $0.0192 | $0.0576
51 | Type-A USB Connector | J5 | USB 2.0 1.5A 2 235℃ Right-Angle 4P+4P Female -40℃~+85℃ Gold Brass Type-A Plugin USB Connectors ROHS | Custom | U224-081N-1BR61 | XKB Connection | - | 1 | 3 | LCSC (https://www.lcsc.com/product-detail/USB-Connectors_XKB-Connection-U224-081N-1BR61_C908455.html) | $0.1726 | $0.5178
52 | Type-A Connector | J6 | USB 3.0 2 Right-Angle 9P+9P Female Type-A Plugin USB Connectors ROHS | Custom | UEA1112C-8HS6-4F | FOXCONN | - | 1 | 3 | LCSC (https://www.lcsc.com/product-detail/USB-Connectors_FOXCONN-UEA1112C-8HS6-4F_C225759.html) | $0.7058 | $2.1174
53 | DC JACK | J7 | Shrouded DC Power Receptacle -20℃~+70℃ 2.5mm 6.5mm 10A 16V Plugin AC/DC Power Connectors ROHS | Custom | DC-053D-25A | Korean Hroparts Elec | - | 1 | 3 | LCSC (https://www.lcsc.com/product-detail/DC-Power-Connector_Korean-Hroparts-Elec-DC-053D-25A_C2686352.html) | $0.4297 | $1.2891
54 | SMA Connector | J8 | 1 Inner bore SMA Board Edge Bend 11mm 5.35mm Plugin RF Connectors / Coaxial Connectors ROHS | Custom | HJ-SMA175 | HJ Tech | - | 1 | 3 | LCSC (https://www.lcsc.com/product-detail/RF-Connectors-Coaxial-Connectors_HJ-Tech-HJ-SMA175_C1509213.html) | $0.8040 | $2.4120
55 | SIM Card Connectors | J10, J11 | Copper Alloy Self bomb Gold plating 1.25mm Deck -40℃~+85℃ 260℃ NanoSIM SMD SIM Card Connectors ROHS | Custom | XKNANO-113 | XKB Connectivity | - | 2 | 6 | LCSC (https://www.lcsc.com/product-detail/SIM-Card-Connectors_XKB-Connection-XKNANO-113_C381071.html) | $0.5500 | $3.3000
56 | Terminal Block | J12, J13, J14, J15, J16 | 250V 10A 3 Bend -40℃~+105℃ 1 3.5mm 1x3P Green Board Edge/Receptacle-Close Push-Pull,P=3.5mm Pluggable System Terminal Block ROHS | Custom | DB2ERC-3.5-3P-GN | DORABO | - | 5 | 15 | LCSC (https://www.lcsc.com/product-detail/Pluggable-System-Terminal-Block_DORABO-DB2ERC-3-5-3P-GN_C430551.html) | $0.0987 | $1.4805
57 | Male Header | J17 | 250V 3A Brick nogging Square Pins 2.5mm 260℃@5S 6mm 20P -40℃~+105℃ 2.54mm 双排 Black 2.54mm 2x10P SMD,P=2.54mm Pin Headers ROHS | Custom | PZ254-2-10-S | HCTL | - | 1 | 3 | LCSC (https://www.lcsc.com/product-detail/Pin-Headers_HCTL-PZ254-2-10-S_C3294468.html) | $0.1892 | $0.5676
58 | UFL Connector | J18 | CONN U.FL RCPT STR 50 OHM SMD | Custom | U.FL-R-SMT-1(80) | Hirose | - | 1 | 3 | Digikey (https://www.digikey.com/en/products/detail/hirose-electric-co-ltd/U-FL-R-SMT-1-80/3978495) | $1.3200 | $3.9600
59 | USB Connector | J19 | CONN RCPT USB2.0 MICRO B SMD R/A | Custom | 10118192-0001LF | Amphenol FCI | - | 1 | 3 | Digikey (https://www.digikey.com/en/products/detail/amphenol-cs-fci/10118192-0001LF/2785387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) | $0.4600 | $1.3800
60 | Wire To Board Connector | J20 | 1x4P 4P XH 1 Tin 2.5mm 4 -25℃~+85℃ Brass 3A Straight Plugin,P=2.5mm Wire To Board Connector ROHS | Custom | XH-4A-L | HCTL | - | 1 | 3 | LCSC (https://www.lcsc.com/product-detail/Wire-To-Board-Connector_HCTL-XH-4A-L_C2979569.html) | $0.0130 | $0.0390
61 | Ethernet Connector | J21, J24 | RJ45 RJReceptacle 1 Internal oscillator included Shrouded WithLED Plugin Ethernet Connectors/Modular Connectors (RJ45 RJ11) ROHS | Custom | HR911130C | HANRUN | - | 2 | 6 | LCSC (https://www.lcsc.com/product-detail/Ethernet-Connectors-Modular-Connectors-RJ45-RJ11_HANRUN-Zhongshan-HanRun-Elec-HR911130C_C50933.html) | $2.5538 | $15.3228
62 | JST Connector | J22 | 1x2P XH 1 2.54mm 2.54mm Male pin 2 -25℃~+85℃ 3A Straight Straight,P=2.5mm Wire To Board / Wire To Wire Connector ROHS | Custom | HC-XH-2A-G | HCTL | - | 1 | 3 | LCSC (https://www.lcsc.com/product-detail/Wire-To-Board-Connector_HCTL-HC-XH-2A-G_C5341201.html) | $0.0152 | $0.0456
63 | Wire To Board Connector | J23 | 1x4P 4P XH 1 Tin 2.5mm 4 -25℃~+85℃ Brass 3A Straight Plugin,P=2.5mm Wire To Board Connector ROHS | Custom | XH-4A | HCTL | - | 1 | 3 | LCSC (https://www.lcsc.com/product-detail/Wire-To-Board-Connector_HCTL-XH-4A_C2908602.html) | $0.0167 | $0.0501
64 | Audio Connector | J25 | 3.5mm headphone jack 1A SMD Audio Connectors ROHS | Custom | PJ-332D-6A | Korean Hroparts Elec | - | 1 | 3 | LCSC (https://www.lcsc.com/product-detail/Audio-Connector-Headphone_Korean-Hroparts-Elec-PJ-332D-6A_C840336.html) | $0.3390 | $1.0170
65 | FFC / FPC Connector | J26 | CONN FFC BOTTOM 30POS 0.5MM R/A | Custom | TF31-30S-0.5SH(800) | Hirose | - | 1 | 3 | Digikey (https://www.digikey.com/en/products/detail/hirose-electric-co-ltd/TF31-30S-0-5SH-800/11204721) | $2.3700 | $7.1100
66 | Wire To Board Connector | J27, J28 | 1x2P 2P XH 1 Tin 2.5mm 2 -25℃~+85℃ Brass 3A Straight Plugin,P=2.5mm Wire To Board Connector ROHS | Custom | XH-2A-Y | HCTL | - | 2 | 6 | LCSC (https://www.lcsc.com/product-detail/Wire-To-Board-Connector_HCTL-XH-2A-Y_C2908595.html) | $0.0069 | $0.0414
67 | USB Connector | J29 | 1 Brick nogging 14P Female Type-C SMD USB Connectors ROHS | Custom | TYPE-C-31-D-07 | Korean Hroparts Elec | - | 1 | 3 | LCSC (https://www.lcsc.com/product-detail/USB-Connectors_Korean-Hroparts-Elec-TYPE-C-31-D-07_C2689965.html) | $0.4942 | $1.4826
68 | Relay | K1, K2, K3, K4, K5 | RELAY TELECOM DPDT 1A 5V | Custom | G6K-2F-Y-TR-DC5 | Omron | - | 5 | 15 | Digikey (https://www.digikey.com/en/products/detail/omron-electronics-inc-emc-div/G6K-2F-Y-TR-DC5/369212) | $4.4900 | $67.3500
69 | Common Mode Choke | L1, L2, L3, L4 | CMC 100MA 2LN 90 OHM SMD | Custom | MCZ1210CH900L2TA0G | TDK | - | 4 | 12 | Digikey (https://www.digikey.be/en/products/detail/tdk-corporation/MCZ1210CH900CPTA0G/17394498) | $0.5400 | $6.4800
70 | Inductor | L5 | Fixed Ind 4.720%UH 0.06 Ohm 3200M | Custom | SWPA4030S4R7MT | Sunlord | 4.7uH | 1 | 3 | Digikey (https://www.digikey.com/en/products/detail/shenzhen-sunlord-electronics-co-ltd/SWPA4030S4R7MT/14119874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) | $0.3900 | $1.1700
71 | Inductor | L6, L9 | FIXED IND 2.2UH 1.5A 160MOHM SMD | Custom | MAKK2016T2R2M | Taiyo Yuden | 2.2uH | 2 | 6 | Digikey (https://www.digikey.com/en/products/detail/taiyo-yuden/MAKK2016T2R2M/4970825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) | $0.2000 | $1.2000
72 | Inductor | L7, L8 | 1uH ±20% 23A SMD,6.6x6.4mm Power Inductors ROHS | Custom | YSPIT0630A-1R0M | YJYCOIN | 1uH | 2 | 6 | LCSC (https://www.lcsc.com/product-detail/Power-Inductors_YJYCOIN-YSPIT0630A-1R0M_C18236293.html) | $0.7956 | $4.7736
73 | LED | LED1 | Emerald 0603 Light Emitting Diodes (LED) ROHS | LED-0603 | NCD0603G2 | Foshan NationStar Optoelectronics | - | 1 | 3 | LCSC (https://www.lcsc.com/product-detail/Light-Emitting-Diodes-LED_Foshan-NationStar-Optoelectronics-NCD0603G2_C87326.html) | $0.0218 | $0.0654
74 | LED | LED2, LED6 | RED LED 0603 Light Emitting Diodes | LED-0603 | NCD0603R3 | Foshan NationStar Optoelectronics | - | 2 | 6 | LCSC (https://www.lcsc.com/product-detail/Light-Emitting-Diodes-LED_Foshan-NationStar-Optoelectronics-NCD0603R3_C3151730.html) | $0.0218 | $0.1308
75 | LED | LED3 | yellow 0603 Light Emitting Diodes (LED) ROHS | LED-0603 | NCD0603Y2 | Foshan NationStar Optoelectronics | - | 1 | 3 | LCSC (https://www.lcsc.com/product-detail/Light-Emitting-Diodes-LED_Foshan-NationStar-Optoelectronics-NCD0603Y2_C89811.html) | $0.0196 | $0.0588
76 | LED | LED4 | LED YELLOW CLEAR CHIP SMD | LED-0402 | XZMYK68W-2 | SunLED | - | 1 | 3 | Digikey (https://www.digikey.com/en/products/detail/sunled/XZMYK68W-2/4745801?s=N4IgTCBcDaIBoC0CyBNA0gNgBwHUC0EAugL5A) | $0.3500 | $1.0500
77 | LED | LED5 | LED RED CLEAR CHIP SMD | LED-0402 | XZMDK68W-2 | SunLED | - | 1 | 3 | Digikey (https://www.digikey.com/en/products/detail/sunled/XZMDK68W-2/4745956?s=N4IgTCBcDaIBoC0CyARA0gNgBwHUC0EAugL5A) | $0.3000 | $0.9000
78 | LED | LED7 | LED BLUE CLEAR 2SMD | LED-0402 | XZCBD68W-2 | SunLED | - | 1 | 3 | Digikey (https://www.digikey.com/en/products/detail/sunled/XZCBD68W-2/4901899?s=N4IgTCBcDaIBoC0DCAhAIgNgBwHUC0EAugL5A) | $0.5100 | $1.5300
79 | RGB LED | LED8, LED9, LED10, LED11, LED12, LED13 | 12mA RGB SMD3535 Light Emitting Diodes (LED) ROHS | SMD3535 | WS2812B-MINI-V3/W | Worldsemi | - | 6 | 18 | LCSC (https://www.lcsc.com/product-detail/RGB-LEDs-Built-in-IC_Worldsemi-WS2812B-MINI-V3-W_C527089.html) | $0.0868 | $1.5624
80 | Mosfet | Q1 | Mosfet 2 N-Channel 20V 485mA 250mW Surface Mount SC-89 (SOT-563F) | SOT-563 | SI1024X-T1-GE3 | Vishay Intertech | - | 1 | 3 | Digikey (https://www.digikey.com/en/products/detail/vishay-siliconix/SI1024X-T1-GE3/1995503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) | $0.5300 | $1.5900
81 | Mosfet | Q2, Q3, Q4, Q5 | SOT-23 MOSFETs ROHS | SOT-23 | FDN335N | TECH PUBLIC | - | 4 | 12 | LCSC (https://www.lcsc.com/product-detail/MOSFETs_UMW-Youtai-Semiconductor-Co-Ltd-FDN335N_C347512.html) | $0.0454 | $0.5448
82 | MOSFET | Q7, Q8, Q9, Q10, Q11 | 30V 100mA 200mW 8Ω@4V,10mA N Channel SOT-23 MOSFETs ROHS | SOT-23 | 2SK3018 | KUU | - | 5 | 15 | Digikey (https://www.digikey.com/en/products/detail/micro-commercial-co/2SK3018-TP/6616090) | $0.4100 | $6.1500
83 | Transistor | Q14 | Trans Gp Bjt NPN 25V 1.5A 300MW 3-PIN SOT-23 T/r | SOT-23 | SS8050-G | Comchip | - | 1 | 3 | Digikey (https://www.digikey.com/en/products/detail/comchip-technology/SS8050-G/6138901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) | $0.2900 | $0.8700
84 | MOSFET | Q15 | MOSFET P-CH 30V 4.3A SOT23-3 | SOT-23 | AOSS21311C | Alpha & Omega Semiconductor | - | 1 | 3 | Digikey (https://www.digikey.com/en/products/detail/alpha-omega-semiconductor-inc/AOSS21311C/11567447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) | $0.4400 | $1.3200
85 | Transistor | Q16 | TRANS NPN 40V 0.2A SOT523 | SOT-523 | MMBT3904T-7-F | Diodes Zetex | - | 1 | 3 | Digikey (https://www.digikey.com/en/products/detail/diodes-incorporated/MMBT3904T-7-F/725021) | $0.2500 | $0.7500
86 | Mosfet | Q17 | 40V 100mW 100@10mA,1V 200mA 300MHz 300mV@50mA,5mA NPN -55℃~+150℃@(Tj) SOT-723 Bipolar Transistors - BJT ROHS | SOT-723 | MMBT3904M | TECH PUBLIC | - | 1 | 3 | LCSC (https://www.lcsc.com/product-detail/Bipolar-Transistors-BJT_TECH-PUBLIC-MMBT3904M_C2923360.html) | $0.0280 | $0.0840
87 | Resistor | R1, R2, R4, R5, R25, R26, R30, R33, R37, R46, R50, R72, R75, R76, R77, R78, R79, R82, R83, R92, R108, R111, R112, R130, R152, R194, R199, R203, R208, R209, R225, R228, R229, R230, R234, R252, R253, R254, R258, R266 | RES 10K OHM 1% 1/16W 0402 | Res-0402 | RC0402FR-0710KL | Yageo | 10K | 40 | 120 | Digikey (https://www.digikey.com/en/products/detail/yageo/RC0402FR-0710KL/726523) | $0.0073 | $0.8760
88 | Resistor | R3, R57, R63, R64, R69, R193 | RES 100K OHM 1% 1/16W 0402 | Res-0402 | RC0402FR-07100KL | Yageo | 100K | 6 | 18 | Digikey (https://www.digikey.com/en/products/detail/yageo/RC0402FR-07100KL/726526) | $0.0150 | $0.2700
89 | Resistor | R6, R7, R34, R41, R47, R115, R264 | RES SMD 1M OHM 5% 1/16W 0402 | Res-0402 | AF0402JR-071ML | Yageo | 1M | 7 | 21 | Digikey (https://www.digikey.com/en/products/detail/yageo/AF0402JR-071ML/5900735) | $0.0240 | $0.5040
90 | Resistor | R8, R9, R97, R98, R99, R100, R101, R132, R133, R134, R135, R136, R137, R138, R139, R156, R160, R161, R163, R164, R165, R166, R167, R168, R169, R170, R171, R172, R210, R211, R212, R213, R214, R215, R216, R217, R218, R219, R220, R221, R238, R248, R249, R250, R251, R259, R260 | RES 4.7K OHM 1% 1/16W 0402 | Res-0402 | RC0402FR-074K7L | Yageo | 4.7K | 47 | 141 | Digikey (https://www.digikey.com/en/products/detail/yageo/RC0402FR-074K7L/2827563) | $0.0073 | $1.0293
91 | Resistor | R10, R73, R74, R80, R81, R237, R265 | RES 1K OHM 1% 1/16W 0402 | Res-0402 | RC0402FR-071KL | Yageo | 1K | 7 | 21 | Digikey (https://www.digikey.com/en/products/detail/yageo/RC0402FR-071KL/726513) | $0.0150 | $0.3150
92 | Resistor | R11, R14, R15, R16, R19, R20, R21, R22, R119, R120, R121, R122, R123, R124, R144, R145, R146, R147, R148, R149, R239, R240, R241, R242, R243, R244, R245, R246 | RES 22 OHM 1% 1/16W 0402 | Res-0402 | RC0402FR-0722RL | Yageo | 22R | 28 | 84 | Digikey (https://www.digikey.com/en/products/detail/yageo/RC0402FR-0722RL/726562) | $0.0088 | $0.7392
93 | ~~Resistor~~ | ~~R12, R13~~ | ~~RES 100 OHM 1% 1/16W 0402~~ | ~~Res-0402~~ | ~~RC0402FR-07100RL~~ | ~~Yageo~~ | ~~DNP~~ | ~~2~~ | ~~6~~ | ~~Digikey~~ | ~~-~~ | ~~-~~ | ~~Do not place~~
94 | ~~Resistor~~ | ~~R17~~ | ~~RES SMD 120 OHM 0.1% 1/10W 0603~~ | ~~Res-0603~~ | ~~RT0603BRB07120RL~~ | ~~Yageo~~ | ~~DNP~~ | ~~1~~ | ~~3~~ | ~~Digikey~~ | ~~-~~ | ~~-~~ | ~~Do not place~~
95 | Resistor | R18 | RES SMD 120 OHM 0.1% 1/10W 0603 | Res-0603 | RT0603BRB07120RL | Yageo | 120R | 1 | 3 | Digikey (https://www.digikey.com/en/products/detail/yageo/RT0603BRB07120RL/5926834) | $0.1346 | $0.4039
96 | Resistor | R23, R24, R28, R29, R52, R53, R54, R60, R65, R68, R84, R85, R86, R87, R88, R89, R90, R116, R129, R142, R173, R174, R177, R178, R191, R247, R255 | RES 0 OHM JUMPER 1/16W 0402 | Res-0402 | RC0402FR-070RL | Yageo | 0R | 27 | 81 | Digikey (https://www.digikey.com/en/products/detail/yageo/RC0402FR-070RL/2827570) | $0.0064 | $0.5184
97 | Resistor Array | R27, R222, R223, R224 | RES ARRAY 4 RES 10K OHM 1206 | Custom | YC164-FR-0710KL | Yageo | 10K | 4 | 12 | Digikey (https://www.digikey.com/en/products/detail/yageo/YC164-FR-0710KL/5952601) | $0.1170 | $1.4040
98 | Resistor | R31, R36, R45, R49 | RES 6.8K OHM 1% 1/16W 0402 | Res-0402 | RC0402FR-076K8L | Yageo | 6.8K | 4 | 12 | Digikey (https://www.digikey.com/en/products/detail/yageo/RC0402FR-076K8L/726642) | $0.0150 | $0.1800
99 | Resistor | R32, R40, R42, R44 | RES SMD 510 OHM 1% 1/16W 0402 | Res-0402 | RT0402FRE07510RL | Yageo | 510R | 4 | 12 | Digikey (https://www.digikey.com/en/products/detail/yageo/RT0402FRE07510RL/1072055) | $0.0270 | $0.3240
100 | Resistor | R35 | RES 22.1K OHM 1% 1/10W 0603 | Res-0603 | RC0603FR-0722K1L | Yageo | 22.1K | 1 | 3 | Digikey (https://www.digikey.com/en/products/detail/yageo/RC0603FR-0722K1L/727058) | $0.0190 | $0.0570
101 | Resistor | R38, R39, R104, R105, R197 | RES 5.1K OHM 1% 1/16W 0402 | Res-0402 | RC0402FR-075K1L | Yageo | 5.1K | 5 | 15 | Digikey (https://www.digikey.com/en/products/detail/yageo/RC0402FR-075K1L/726624) | $0.0150 | $0.2250
102 | Resistor | R43 | RES 47.5K OHM 1% 1/10W 0603 | Res-0603 | RC0603FR-0747K5L | Yageo | 47.5K | 1 | 3 | Digikey (https://www.digikey.com/en/products/detail/yageo/RC0603FR-0747K5L/727255) | $0.1000 | $0.3000
103 | Resistor | R51 | RES 2.7K OHM 1% 1/10W 0603 | Res-0603 | RC0603FR-072K7L | Yageo | 2.7K | 1 | 3 | Digikey (https://www.digikey.com/en/products/detail/yageo/RC0603FR-072K7L/727032) | $0.1000 | $0.3000
104 | Resistor | R55 | RES SMD 330R 100 mW 0603 | Res-0603 | RC0603JR-07330RL | Yageo | 330R | 1 | 3 | Digikey (https://www.digikey.com/en/products/detail/yageo/RC0603JR-07330RL/726769) | $0.1000 | $0.3000
105 | ~~Resistor~~ | ~~R56~~ | ~~RES 100K OHM 1% 1/16W 0402~~ | ~~Res-0402~~ | ~~RC0402FR-07100KL~~ | ~~Yageo~~ | ~~DNP~~ | ~~1~~ | ~~3~~ | ~~Digikey~~ | ~~-~~ | ~~-~~ | ~~Do not place~~
106 | Resistor | R58, R66, R198 | RES 12K OHM 1% 1/16W 0402 | Res-0402 | RC0402FR-0712KL | Yageo | 12K | 3 | 9 | Digikey (https://www.digikey.com/en/products/detail/yageo/RC0402FR-0712KL/726532) | $0.1000 | $0.9000
107 | Resistor | R59, R67 | RES 39K OHM 1% 1/16W 0402 | Res-0402 | RC0402FR-0739KL | Yageo | 39K | 2 | 6 | Digikey (https://www.digikey.com/en/products/detail/yageo/RC0402FR-0739KL/726601) | $0.1000 | $0.6000
108 | ~~Resistor~~ | ~~R61, R205~~ | ~~RES 0 OHM JUMPER 1/16W 0402~~ | ~~Res-0402~~ | ~~RC0402FR-070RL~~ | ~~Yageo~~ | ~~DNP~~ | ~~2~~ | ~~6~~ | ~~Digikey~~ | ~~-~~ | ~~-~~ | ~~Do not place~~
109 | Resistor | R62, R233 | RES SMD 1K OHM 1% 1/10W 0603 | Res-0603 | CRCW06031K00FKEA | Vishay Dale | 1K | 2 | 6 | Digikey (https://www.digikey.com/en/products/detail/vishay-dale/CRCW06031K00FKEA/1174668) | $0.1000 | $0.6000
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
